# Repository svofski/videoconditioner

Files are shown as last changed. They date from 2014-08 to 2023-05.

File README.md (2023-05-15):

# Non-standard RGB video conditioner
RGB video input for Altera DE1 board + PAL Modulator
====================================================
This is an experimental video capture project. 
The goal is to capture poorly modulated RGB + Sync signal as produced by an old Soviet home PC,
detect sync, massage the signal levels, insert correct sync pulses, add PAL colour modulation
and output a signal that would be acceptable by a modern colour TV.

Вектор-06ц is the particular computer that I had in mind. Its video generation circuit is
infamous for blatant disregard of all existing video standards at once, which makes it
rather difficult to connect it to modern monitors and televisions.

Outline
-------
The main platform is Altera DE1 FPGA board. It is fairly outdated, but it's the one that I have
on my bench. Going up to more modern FPGA kits is easy.

A working PAL modulator that works well in my [vector06cc FPGA
replica](https://github.com/svofski/vector06cc) of the same computer already exists.

To sample RGB + Sync video signal one needs a decent speed ADC, preferrably with 4 channels,
or a special video capture chip. I found nothing that would suit the job easily available.
However, I found out about a neat trick of using LVDS input pairs available on FPGA chips
to implement custom sigma-delta ADC. No need for special chips!

The basic working principles of such ADC are described in the paper called
["Leveraging FPGA and CPLD digital logic to implement analog to digital converters"](http://www.embedded.com/design/configurable-systems/4008891/Leveraging-FPGA-and-CPLD-digital-logic-to-implement-analog-to-digital-converters) 
by Ted Marena. There's also an excellent explanation and demonstration of the principle in [One Bit ADC](http://www.youtube.com/watch?v=DTCtx9eNHXE)
video by Jeri Ellsworth.

Block diagram
-------------
Here's a simplified diagram of the project:

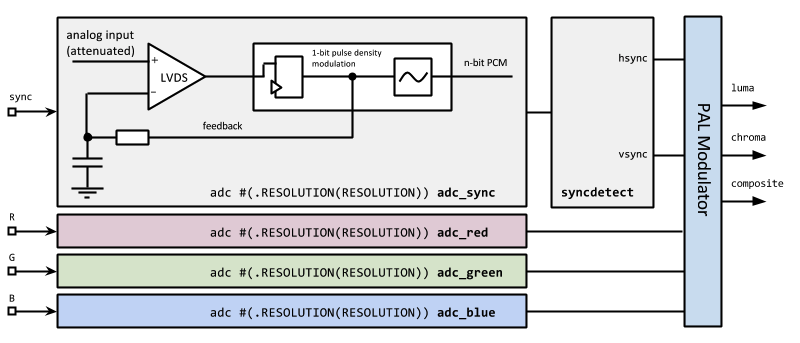
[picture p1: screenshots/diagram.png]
Diagram


The video signal comprised of H+V composite sync and R, G, B signals is level-shifted to be within
range of LVDS inputs (see schematic) and is fed into the ADC. The ADC modules feed back the resulting
PDM signal to the negative side of LVDS inputs, and to the input averaging filter. The recovered
PCM signal is formed on the output of the filter. There are variations of input filters in the source code.

The recovered sync signal is passed to the input of sync detector module, which tries its best to 
recover horizontal and vertical sync pulses. It's designed to be able to cope with bizarre sync signals
produced by bizarre computers. It does the job with variable success. Usually the problems are of electrical
rather than of logical nature. For example, Вектор-06ц is known to have no equalization pulses, which
results in huge amplitude jumps during vertical sync or even simply empty lines.

The resulting sync, R, G, B signals are fed into the video generator module. It consists of sync generator
and PAL modulator. The outputs are chroma, luma and mixed CVBS composite signals. They are output either
using primitive linear DAC on VGA connector of DE1 board, or using a sigma-delta modulator. The latter
allows for having separate luma + chroma (S-Video) signals on the output. 

Generating output
-----------------
S-video using a sigma-delta DAC is very simple:
```
reg [DAC_RESOLUTION:0] ydac;
reg [DAC_RESOLUTION:0] cdac;
always @(posedge clk_out)
begin
    ydac <= ydac[DAC_RESOLUTION-1:0] + tv_luma[RESOLUTION-1:RESOLUTION-DAC_RESOLUTION]; 
    cdac <= cdac[DAC_RESOLUTION-1:0] + tv_chroma[RESOLUTION-1:RESOLUTION-DAC_RESOLUTION]; 
end

assign GPIO_0[10] = ydac[DAC_RESOLUTION];
assign GPIO_0[11] = cdac[DAC_RESOLUTION];
```

Linear DAC on VGA pins of DE1 board is more interesting. The resistor DAC on DE1 allows 4 bits per channel,
or just 16 levels. This is not a lot for composite analog video. Here's what a saw waveform looks like
if only 4 bits are used:

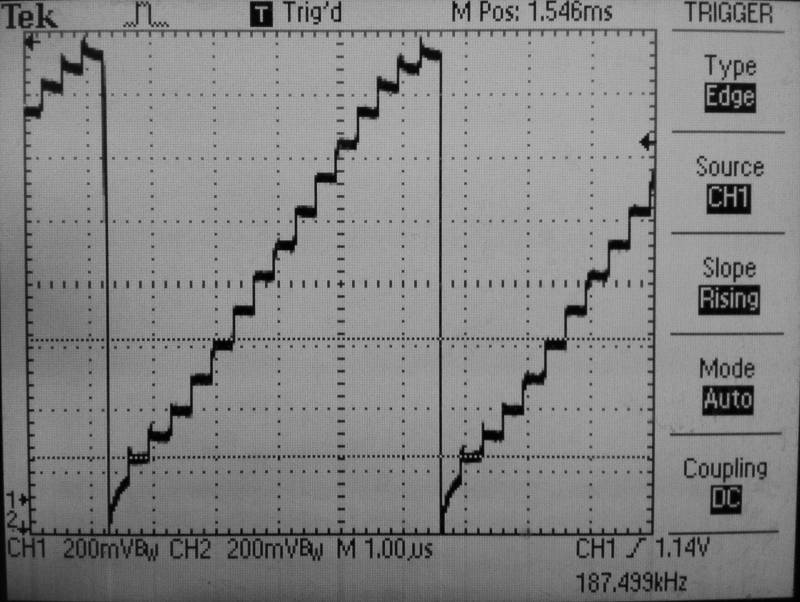
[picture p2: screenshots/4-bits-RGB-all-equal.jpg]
4 bits DAC saw wave
 

However with a little bit of magic, [described in detail in my article here](http://sensi.org/~svo/de1videodac/),
it is possible to get much higher resolution from this DAC. Here's an example:

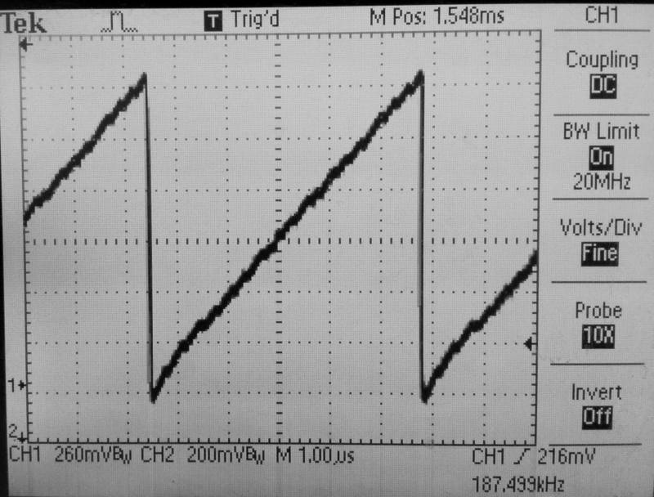
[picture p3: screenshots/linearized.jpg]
Linearized saw wave


The magic DAC is implemented using a look-up table:
```
dactable dactaklakpak(.address(tv_cvbs), .clock(clkpalFSC), .q(dacval));
assign VGA_R = dacval[3:0];
assign VGA_G = dacval[7:4];
assign VGA_B = dacval[11:8];
```

Project files
=============
 * [hw](https://github.com/svofski/videoconditioner/tree/vector06c/hw) contains KiCad files for the DE1 addon board. Check out the [schematic](https://github.com/svofski/videoconditioner/tree/vector06c/hw/videoadc.pdf).
 * [iverilog](https://github.com/svofski/videoconditioner/tree/vector06c/iverilog) contains simulation of video signals as produced by BK-0010, and their detection
 * [src](https://github.com/svofski/videoconditioner/tree/vector06c/src) Altera Quartus II project and synthesizable core

Results
=======
The input board looks like this:

ADC (https://www.flickr.com/photos/svofski/14707757370/)

Single channel, B&W+Sync only with BK-0010:

BK-0010 (https://www.flickr.com/photos/svofski/14770105076/)

Single channel passthrough from C64. Signal sampled and output on DE1 VGA pins without any conditioning. Image credit: Deus ex Machina by Crest/Oxyron.

Graphics by Crest/Oxyron (https://www.flickr.com/photos/svofski/14606473808/)

RGB+Sync from Vector-06c, internally PAL modulated in FPGA (captured by TV tuner)

Vector-06c b2m test (https://www.flickr.com/photos/svofski/14721995768/)

[Work log on a forum (in Russian)](http://zx-pk.ru/showthread.php?t=23833)

Conclusion
==========
This is a research project and I never made it into a finished box with just power plug
and connectors. It works, but is not perfect. The results on my monitor are acceptable.
There were some problems with PAL encoding that I could not resolve that I observed on a couple of older TV sets. 
They are not related to the main focus of the project however: sampling video signals using nothing but a few LVDS pins.

It is definitely possible to capture low-spec video signals with a 10 year old FPGA using
only a few additional discrete components. The practical aspects of this
depend on the situation. Where reliability matter and source signal is known to be
within the specifications, a dedicated chip
like TVP7002 would most likely do better. One interesting example of a project that uses TVP7002
is [Grabor](http://www.rpg.fi/desaster/blog/2013/04/19/vga-framegrabbing-with-tvp7002/).
But with a such chip I would not be able to extract nonstandard 
video signal from Вектор-06ц, just like my monitor cannot do that. Where flexibility and fine control is
required, being able to implement video decoding on the lowest possible level can be beneficial.

The quality of input suffers from quite a bit of noise. I believe part of this is due to really
long electrical connections that are hard to shorten because of the way the connectors on the board are done.
In case of practical application it should be possible to improve the noise characteristics by
implementing the inputs using shorter, carefully layed out trace pairs, hopefully reducing parasitic
capacitance of the connections, thus allowing higher sampling frequency. Finding an optimal configuration
of PCB layout for such application would be an interesting project in itself.

References
==========
 - [Leveraging FPGA and CPLD Digital Logic to Implement Analog To Digital Converters](https://github.com/svofski/videoconditioner/tree/vector06c/whitepapers/CreatingAnADCUsingFPGAResources.PDF) LatticeSemi Whitepaper
 - [Simple Sigma-Delta ADC](https://github.com/svofski/videoconditioner/tree/vector06c/whitepapers/SimpleSigmaDeltaADCDocumentation.PDF) LatticeSemi RD1066
 - [FPGA RGB2VGA](https://sites.google.com/site/tandycocoloco/rgb2vga) scan doubler project by Felipe Antoniosi uses LVDS inputs to implement a successive approximation ADC

-------

2014-2015 Viacheslav Slavinsky, https://www.sensi.org/~svo

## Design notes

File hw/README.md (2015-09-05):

These are KiCAD design files for Video ADC addon for DE1 FPGA Board.

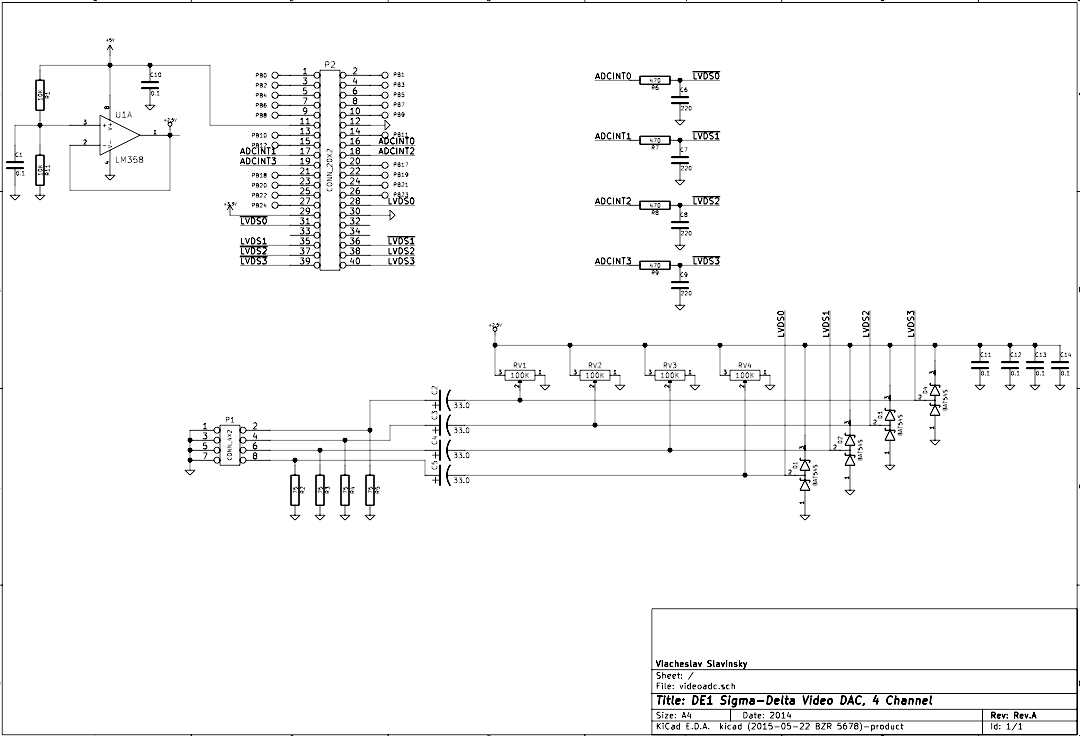
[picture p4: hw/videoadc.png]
The circuit


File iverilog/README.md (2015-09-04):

Simulation files
----------------

This is a sandbox for testing video sync detection code.

- [syncdetect.v](syncdetect.v) is both simulated and synthesizable.
- [simulation.v](simulation.v) is the testbench.

The testbench requires Icarus Verilog to run the simulation and GTKWave to display resulting waveforms. 
If everything is installed, typing ```make``` should run the current simulation. It will produce
```syncdetect.vcd```, which can be viewed with GTKWave. 

Interesting waveforms are cvbs (view as analog), hsync, vsync, porch.

![screenshot](/screenshots/gtkwave.png)

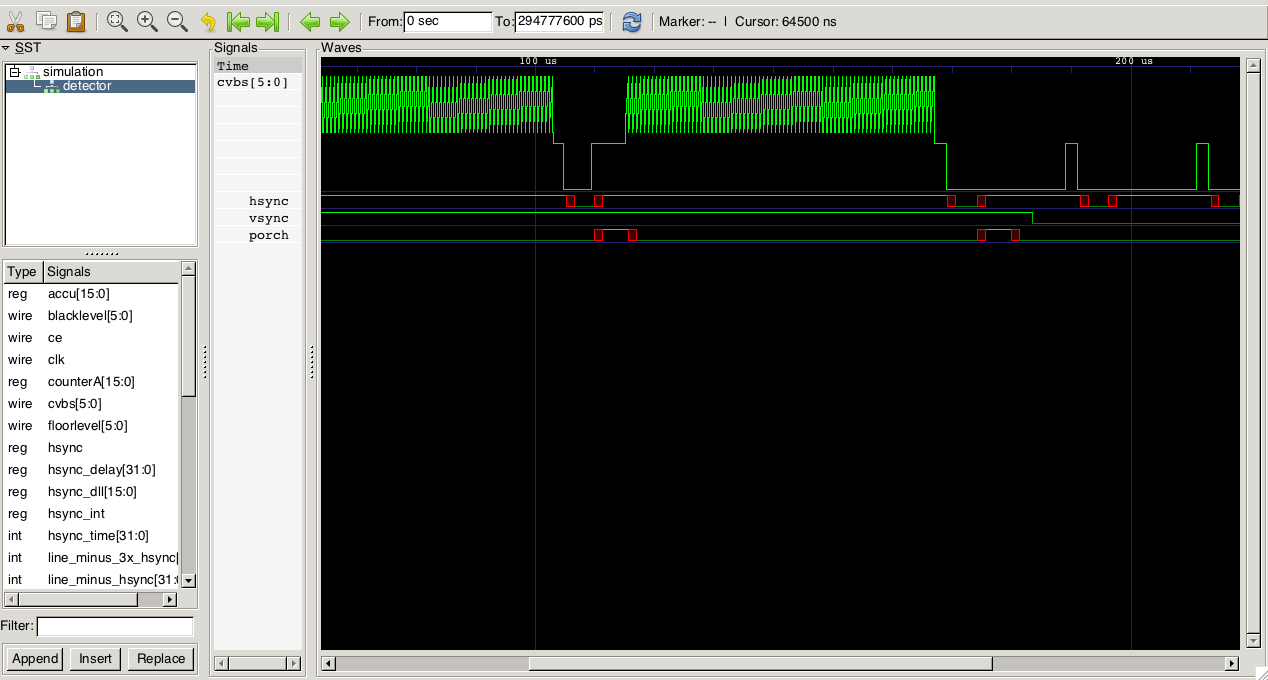
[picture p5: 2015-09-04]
screenshots/gtkwave.png

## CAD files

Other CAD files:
stp1.stp

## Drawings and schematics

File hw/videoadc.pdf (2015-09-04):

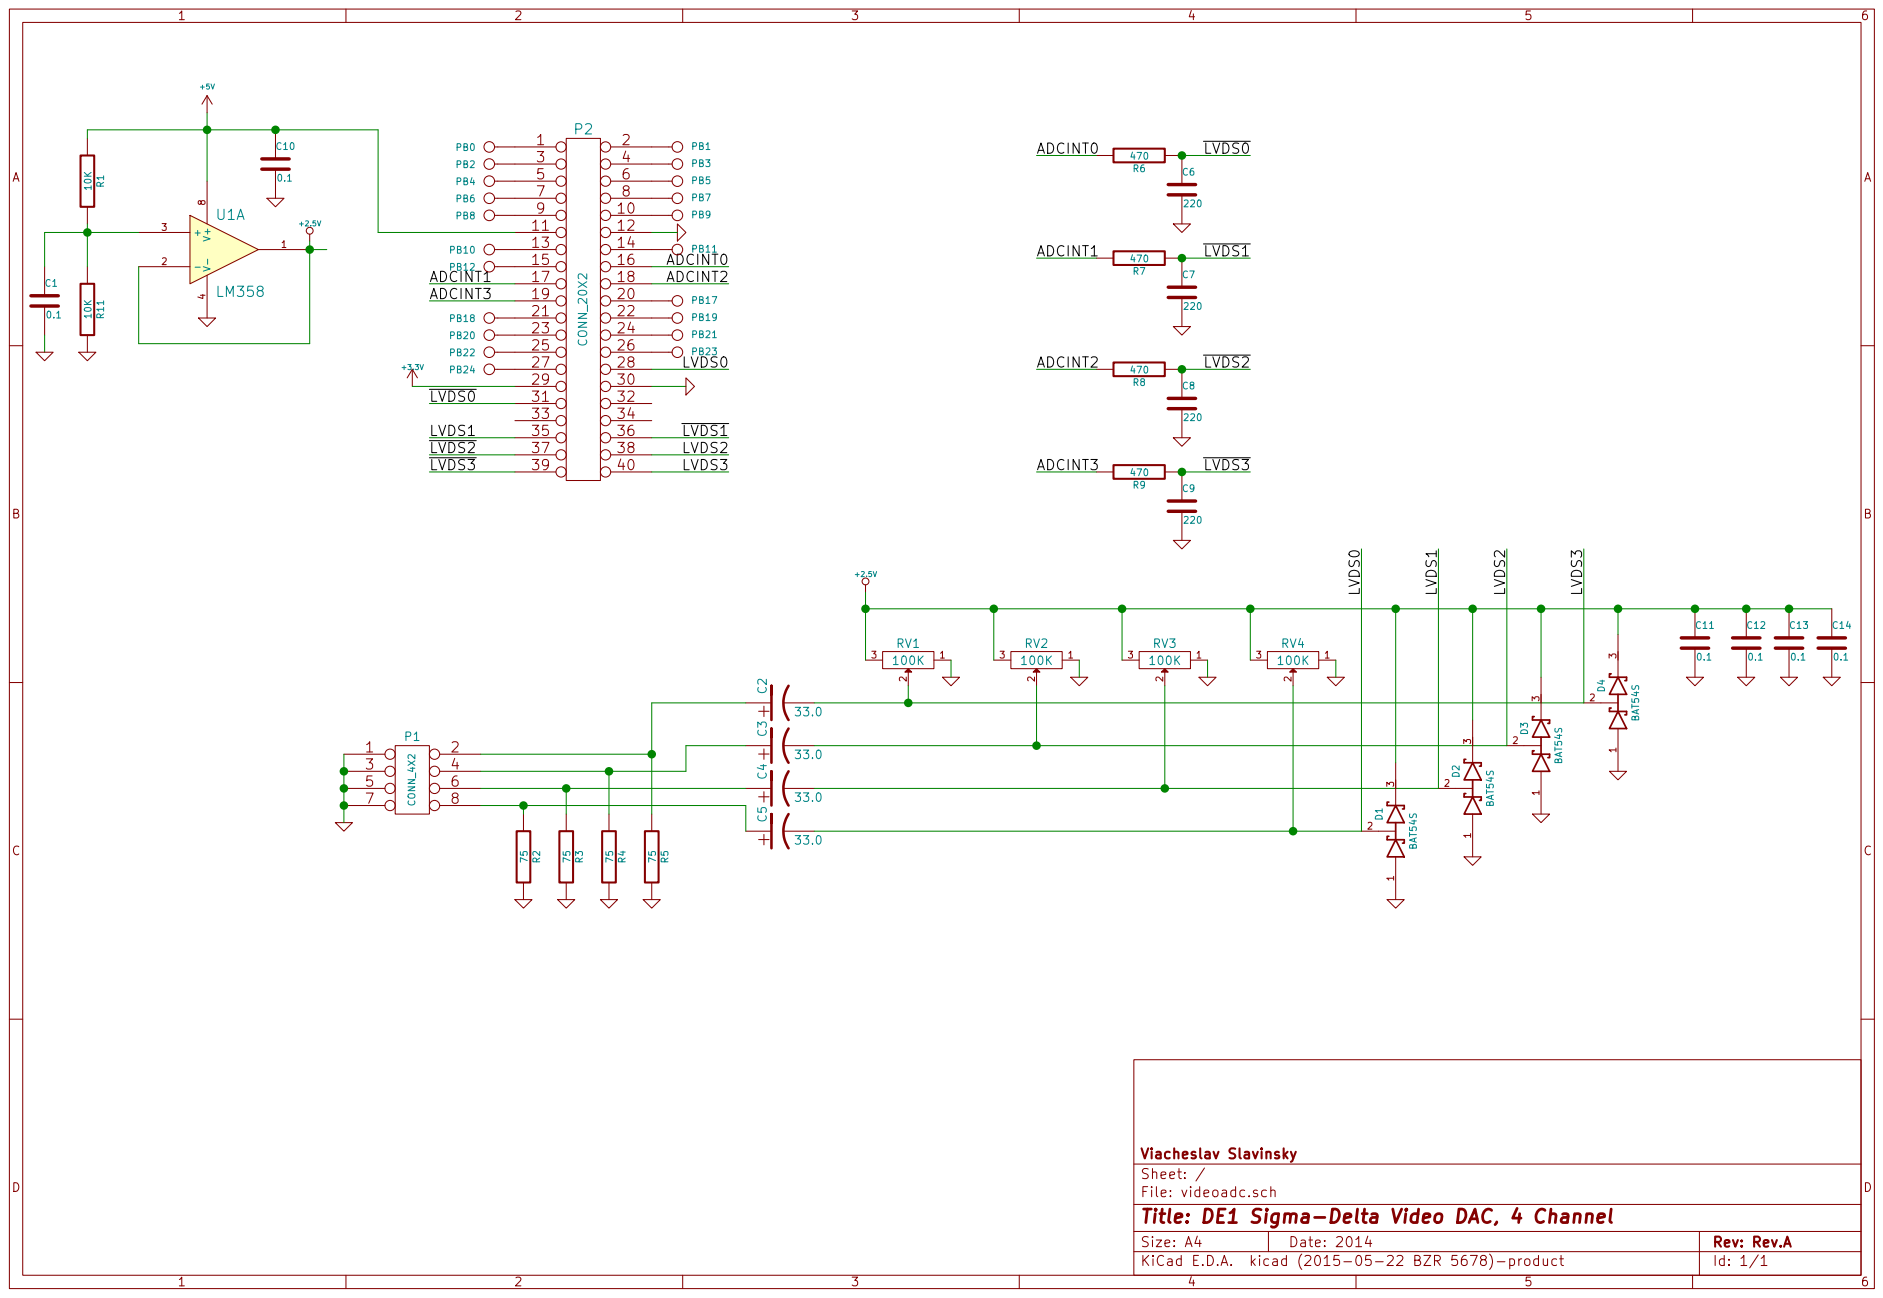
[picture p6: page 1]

Id: 1/1 Title: DE1 Sigma-Delta Video DAC, 4 Channel File: videoadc.sch Sheet: / Viacheslav Slavinsky

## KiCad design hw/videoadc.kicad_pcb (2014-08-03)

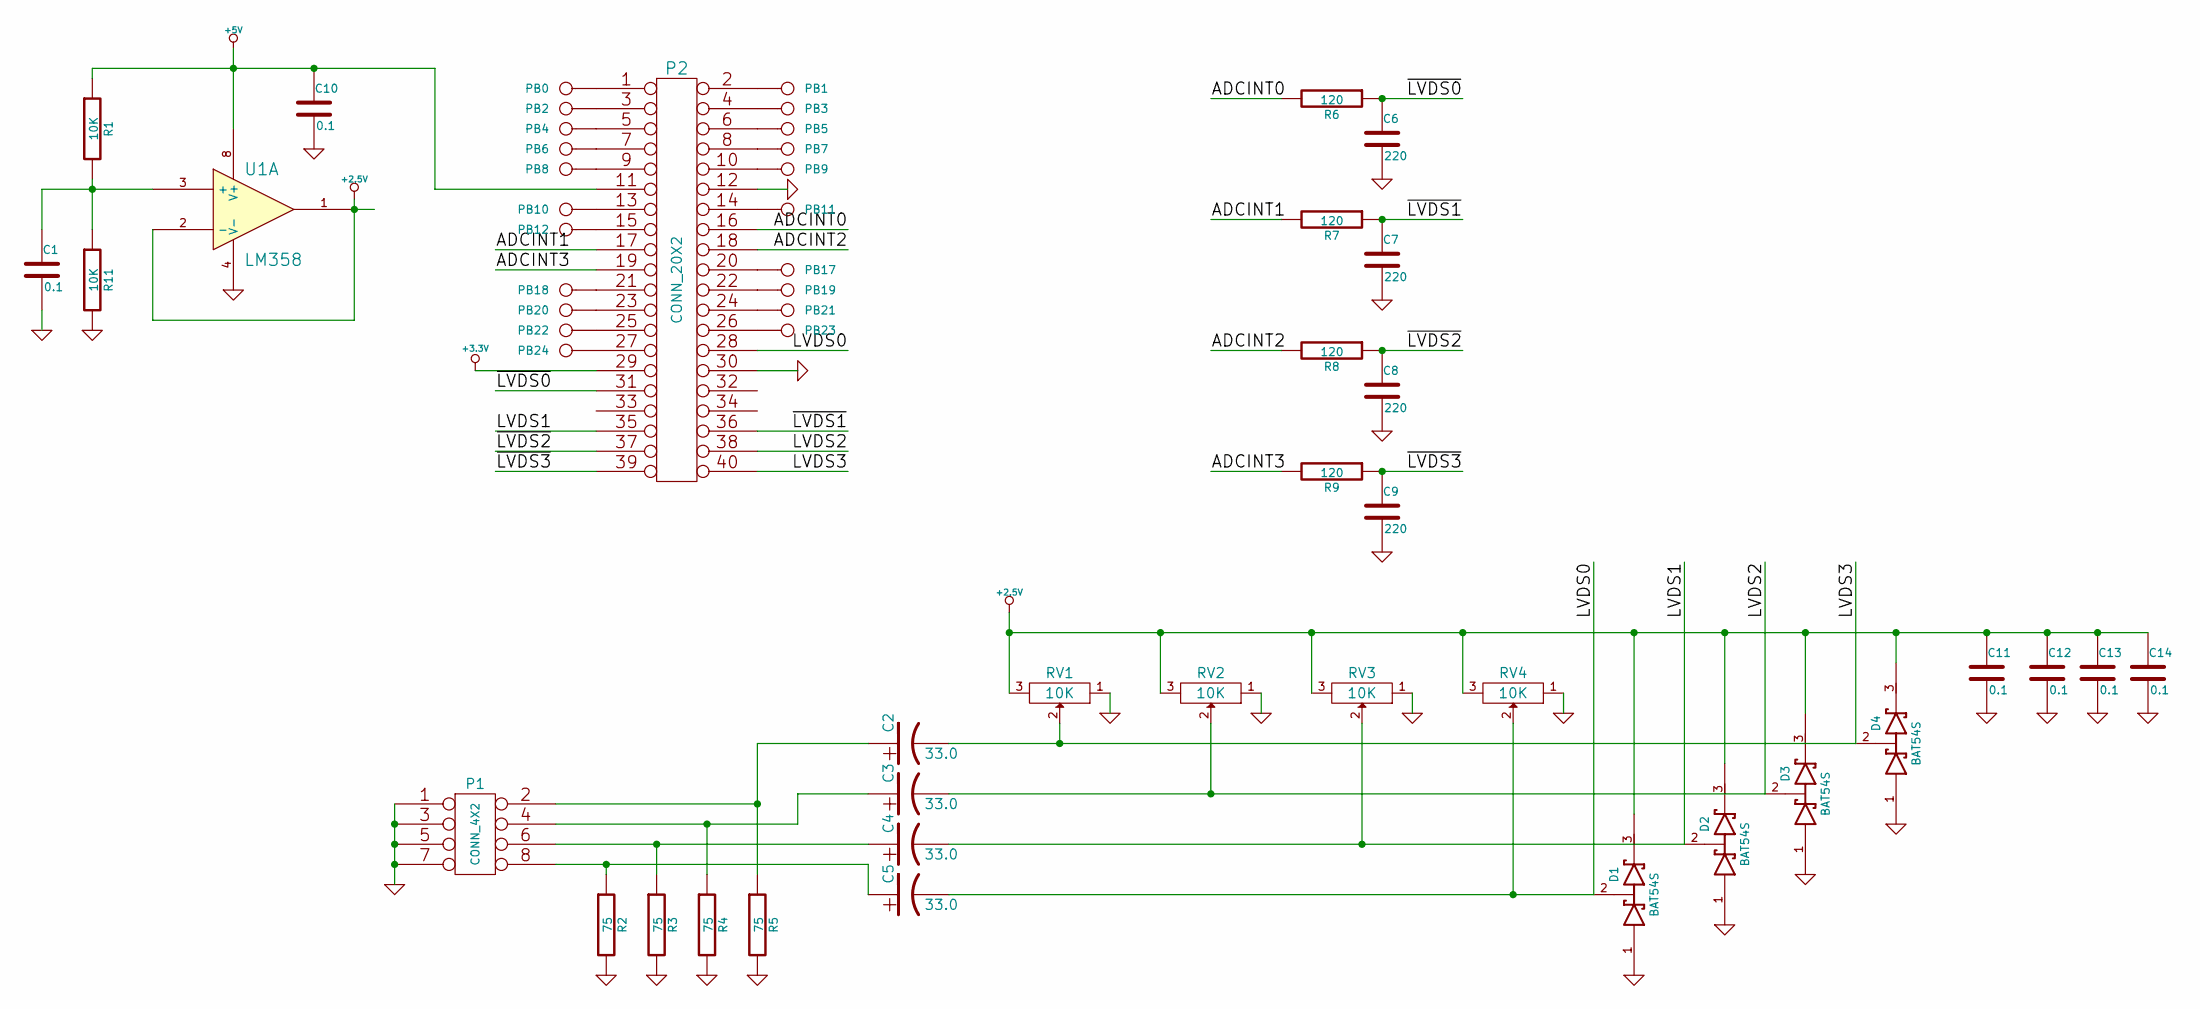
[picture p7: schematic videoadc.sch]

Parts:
C1, C10, C11, C12, C13, C14: 0.1
C2, C3, C4, C5: 33.0
C6, C7, C8, C9: 220
D1, D2, D3, D4: BAT54S
P1: CONN_4X2
P2: CONN_20X2
PB0, PB1, PB2, PB3, PB4, PB5, PB6, PB7, PB8, PB9, PB10, PB11, PB12, PB17, PB18, PB19, PB20, PB21, PB22, PB23, PB24: CONN_1
R1, R11: 10K
R2, R3, R4, R5: 75
R6, R7, R8, R9: 120
RV1, RV2, RV3, RV4: 10K
U1: LM358

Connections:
+2.5V: C11.1, C12.1, C13.1, C14.1, D1.3 (cathode), D2.3 (cathode), D3.3 (cathode), D4.3 (cathode), RV1.3, RV2.3, RV3.3, RV4.3, U1.1, U1.2 (-)
+3.3V: P2.29
+5V: C10.1, P2.11, R1.1, U1.8 (V+)
/ADCINT0: P2.16, R6.2
/ADCINT1: P2.17, R7.2
/ADCINT2: P2.18, R8.2
/ADCINT3: P2.19, R9.2
/LVDS0: C5.2, D1.2 (AK), P2.28, RV4.2
/LVDS1: C4.2, D2.2 (AK), P2.35, RV3.2
/LVDS2: C3.2, D3.2 (AK), P2.38, RV2.2
/LVDS3: C2.2, D4.2 (AK), P2.40, RV1.2
/~LVDS0: C6.1, P2.31, R6.1
/~LVDS1: C7.1, P2.36, R7.1
/~LVDS2: C8.1, P2.37, R8.1
/~LVDS3: C9.1, P2.39, R9.1
GND: C1.2, C6.2, C7.2, C8.2, C9.2, C10.2, C11.2, C12.2, C13.2, C14.2, D1.1 (Anode), D2.1 (Anode), D3.1 (Anode), D4.1 (Anode), P1.1, P1.3, P1.5, P1.7, P2.12, P2.30, R2.2, R3.2, R4.2, R5.2, R11.2, RV1.1, RV2.1, RV3.1, RV4.1, U1.4 (V-)
unnamed: C1.1, R1.2, R11.1, U1.3 (+)
unnamed: C2.1, P1.2, R5.1
unnamed: C3.1, P1.4, R4.1
unnamed: C4.1, P1.6, R3.1
unnamed: C5.1, P1.8, R2.1
unnamed: P2.1, PB0.1
unnamed: P2.2, PB1.1
unnamed: P2.3, PB2.1
unnamed: P2.4, PB3.1
unnamed: P2.5, PB4.1
unnamed: P2.6, PB5.1
unnamed: P2.7, PB6.1
unnamed: P2.8, PB7.1
unnamed: P2.9, PB8.1
unnamed: P2.10, PB9.1
unnamed: P2.13, PB10.1
unnamed: P2.14, PB11.1
unnamed: P2.15, PB12.1
unnamed: P2.20, PB17.1
unnamed: P2.21, PB18.1
unnamed: P2.22, PB19.1
unnamed: P2.23, PB20.1
unnamed: P2.24, PB21.1
unnamed: P2.25, PB22.1
unnamed: P2.26, PB23.1
unnamed: P2.27, PB24.1

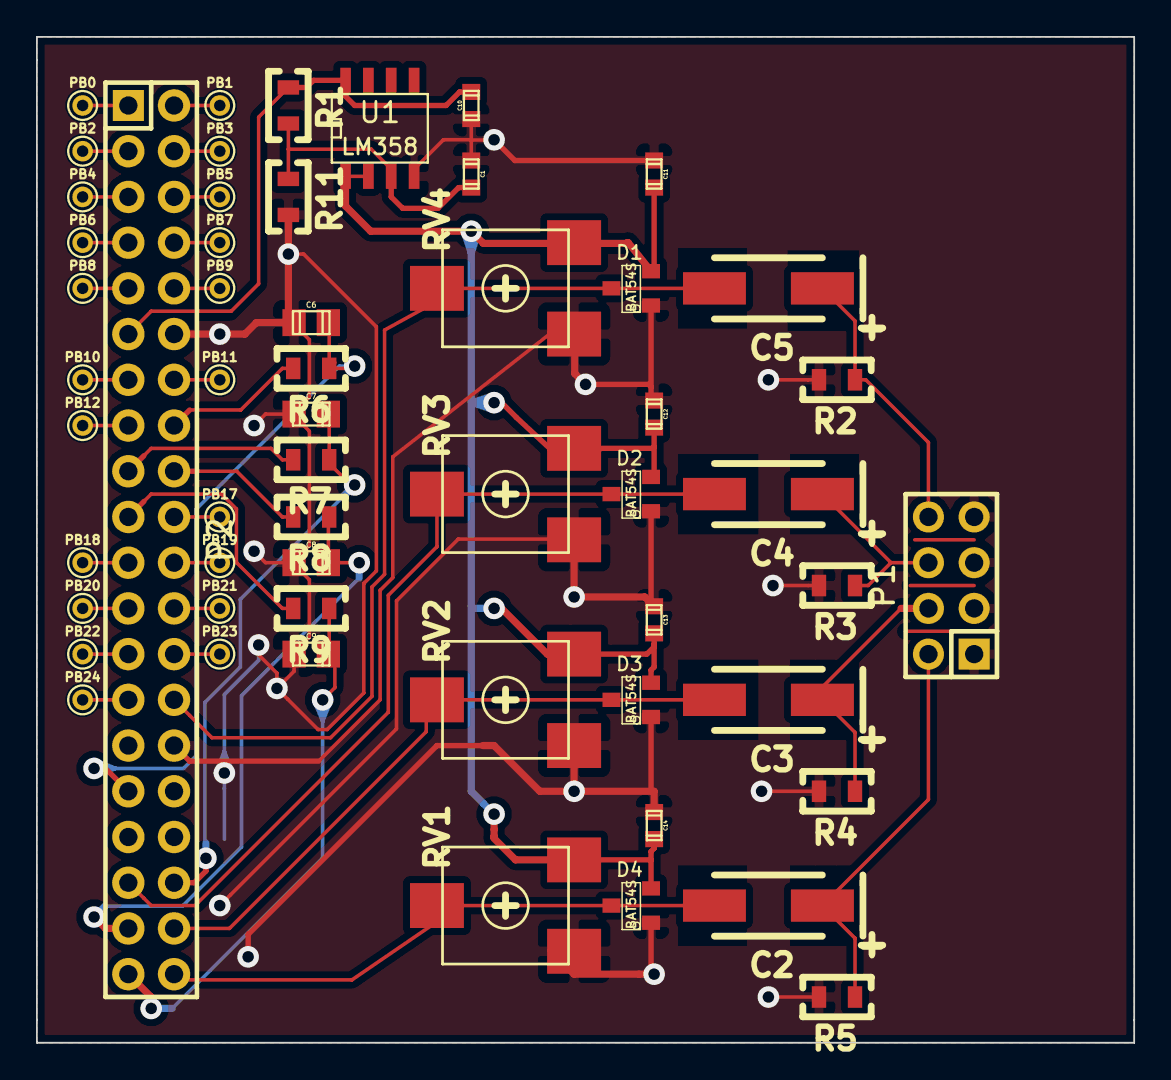
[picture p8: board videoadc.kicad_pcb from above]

Board: 2 copper layers, 61.0 x 55.9 mm, 56 parts (0 on the bottom side), 41 nets.

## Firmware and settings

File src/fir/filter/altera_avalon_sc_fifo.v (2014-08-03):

// -----------------------------------------------------------
// Legal Notice: (C)2007 Altera Corporation. All rights reserved.  Your
// use of Altera Corporation's design tools, logic functions and other
// software and tools, and its AMPP partner logic functions, and any
// output files any of the foregoing (including device programming or
// simulation files), and any associated documentation or information are
// expressly subject to the terms and conditions of the Altera Program
// License Subscription Agreement or other applicable license agreement,
// including, without limitation, that your use is for the sole purpose
// of programming logic devices manufactured by Altera and sold by Altera
// or its authorized distributors.  Please refer to the applicable
// agreement for further details.
//
// Description: Single clock Avalon-ST FIFO.
// -----------------------------------------------------------

`timescale 1 ns / 1 ns


//altera message_off 10036
module altera_avalon_sc_fifo
#(
    // --------------------------------------------------
    // Parameters
    // --------------------------------------------------
    parameter SYMBOLS_PER_BEAT  = 1,
    parameter BITS_PER_SYMBOL   = 8,
    parameter FIFO_DEPTH        = 16,
    parameter CHANNEL_WIDTH     = 0,
    parameter ERROR_WIDTH       = 0,
    parameter USE_PACKETS       = 0,
    parameter USE_FILL_LEVEL    = 0,
    parameter USE_STORE_FORWARD = 0,
    parameter USE_ALMOST_FULL_IF = 0,
    parameter USE_ALMOST_EMPTY_IF = 0,

    // --------------------------------------------------
    // Empty latency is defined as the number of cycles
    // required for a write to deassert the empty flag.
    // For example, a latency of 1 means that the empty
    // flag is deasserted on the cycle after a write.
    //
    // Another way to think of it is the latency for a
    // write to propagate to the output. 
    // 
    // An empty latency of 0 implies lookahead, which is
    // only implemented for the register-based FIFO.
    // --------------------------------------------------
    parameter EMPTY_LATENCY     = 3,
    parameter USE_MEMORY_BLOCKS = 1,

    // --------------------------------------------------
    // Internal Parameters
    // --------------------------------------------------
    parameter DATA_WIDTH  = SYMBOLS_PER_BEAT * BITS_PER_SYMBOL,
    parameter EMPTY_WIDTH = log2ceil(SYMBOLS_PER_BEAT)
)
(
    // --------------------------------------------------
    // Ports
    // --------------------------------------------------
    input                       clk,
    input                       reset,

    input [DATA_WIDTH-1: 0]     in_data,
    input                       in_valid,
    input                       in_startofpacket,
    input                       in_endofpacket,
    input [((EMPTY_WIDTH>0) ? (EMPTY_WIDTH-1):0) : 0]     in_empty,
    input [((ERROR_WIDTH>0) ? (ERROR_WIDTH-1):0) : 0]     in_error,
    input [((CHANNEL_WIDTH>0) ? (CHANNEL_WIDTH-1):0): 0]  in_channel,
    output                      in_ready,

    output [DATA_WIDTH-1 : 0]   out_data,
    output reg                  out_valid,
    output                      out_startofpacket,
    output                      out_endofpacket,
    output [((EMPTY_WIDTH>0) ? (EMPTY_WIDTH-1):0) : 0]    out_empty,
    output [((ERROR_WIDTH>0) ? (ERROR_WIDTH-1):0) : 0]    out_error,
    output [((CHANNEL_WIDTH>0) ? (CHANNEL_WIDTH-1):0): 0] out_channel,
    input                       out_ready,

    input [(USE_STORE_FORWARD ? 2 : 1) : 0]   csr_address,
    input                       csr_write,
    input                       csr_read,
    input [31 : 0]              csr_writedata,
    output reg [31 : 0]         csr_readdata,

    output  wire                almost_full_data,
    output  wire                almost_empty_data
);

    // --------------------------------------------------
    // Local Parameters
    // --------------------------------------------------
    localparam ADDR_WIDTH   = log2ceil(FIFO_DEPTH);
    localparam DEPTH        = FIFO_DEPTH;
    localparam PKT_SIGNALS_WIDTH = 2 + EMPTY_WIDTH;
    localparam PAYLOAD_WIDTH     = (USE_PACKETS == 1) ? 
                   2 + EMPTY_WIDTH + DATA_WIDTH + ERROR_WIDTH + CHANNEL_WIDTH:
                   DATA_WIDTH + ERROR_WIDTH + CHANNEL_WIDTH;

    // --------------------------------------------------
    // Internal Signals
    // --------------------------------------------------
    genvar i;

    reg [PAYLOAD_WIDTH-1 : 0] mem [DEPTH-1 : 0];
    reg [ADDR_WIDTH-1 : 0]  wr_ptr;
    reg [ADDR_WIDTH-1 : 0]  rd_ptr;
    reg [DEPTH-1      : 0]  mem_used;

    wire [ADDR_WIDTH-1 : 0] next_wr_ptr;
    wire [ADDR_WIDTH-1 : 0] next_rd_ptr;
    wire [ADDR_WIDTH-1 : 0] incremented_wr_ptr;
    wire [ADDR_WIDTH-1 : 0] incremented_rd_ptr;

    wire [ADDR_WIDTH-1 : 0] mem_rd_ptr;

    wire read;
    wire write;

    reg empty;
    reg next_empty;
    reg full;
    reg next_full;

    wire [PKT_SIGNALS_WIDTH-1 : 0] in_packet_signals;
    wire [PKT_SIGNALS_WIDTH-1 : 0] out_packet_signals;
    wire [PAYLOAD_WIDTH-1 : 0] in_payload;
    reg  [PAYLOAD_WIDTH-1 : 0] internal_out_payload;
    reg  [PAYLOAD_WIDTH-1 : 0] out_payload;

    reg  internal_out_valid;
    wire internal_out_ready;

    reg  [ADDR_WIDTH : 0] fifo_fill_level;
    reg  [ADDR_WIDTH : 0] fill_level;

    reg  [ADDR_WIDTH-1 : 0]   sop_ptr = 0;
    reg  [23:0]   almost_full_threshold;
    reg  [23:0]   almost_empty_threshold;
    reg  [23:0]   cut_through_threshold;
    reg  [15:0]   pkt_cnt;
    reg  [15:0]   pkt_cnt_r;
    reg  [15:0]   pkt_cnt_plusone;
    reg  [15:0]   pkt_cnt_minusone;
    reg           drop_on_error_en;
    reg           error_in_pkt;
    reg           pkt_has_started;
    reg           sop_has_left_fifo;
    reg           fifo_too_small_r;
    reg           pkt_cnt_eq_zero;
    reg           pkt_cnt_eq_one;
    reg           pkt_cnt_changed;

    wire          wait_for_threshold;
    reg           pkt_mode;
    wire          wait_for_pkt;
    wire          ok_to_forward;
    wire          in_pkt_eop_arrive;
    wire          out_pkt_leave;
    wire          in_pkt_start;
    wire          in_pkt_error;
    wire          drop_on_error;
    wire          fifo_too_small;
    wire          out_pkt_sop_leave;
    wire [31:0]   max_fifo_size;
    reg           fifo_fill_level_lt_cut_through_threshold;
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

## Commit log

2014-08-03 i don't get it...
    [stp1_auto_stripped.stp]
2014-08-03 kkk
    ,,,
    [stp1.stp, videoadc.kicad_pcb, videoadc.sch]
2014-08-05 advances
    this is for 470 ohm / 220 pF filter, which seems to be ringing less and
    therefore filter better
    - the filter is now fc=0.025 (0.1)
    - adaptive threshold/black level
    - 6-bit linear DAC on VGA connector + some test signals
2014-08-09 attempt to make a locked loop for hsync (untested)
    keep 64us loop como sea, but correct it on negative pulses — should
    work great with vector-06c kind of sync
    it should be easy to add horizontal offset now, just pass hsync through
    a delay
2014-08-10 decent sync verified on real vector-06c
    - horizontal delay added (32)
    - vsync shortened by half
    result: frame well centered
    back porch added so blue/gray stands out above black now, but it's not
    delayed with hsync so perhaps not ideal
2014-08-12 full color ADC works
    levels still need some tuning, especially blue appears to be more like
    on/off
    [stp1.stp]
2014-08-13 tweaks tweaks tweaks
    also updated the schematic with actual values
    [videoadc.sch]
2014-08-14 restored color intensity to lower value
    …because the monitor doesn't like too much of it
2015-09-03 schematic fluff
    [videoadc.sch]
2015-09-04 schematic in png
2015-09-04 bw schematic
